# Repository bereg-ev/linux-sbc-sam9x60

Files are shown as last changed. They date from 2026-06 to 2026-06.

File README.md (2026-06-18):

# linux-sbc-sam9x60

In 2019, when I finally decided to quit Eagle PCB and move over to KiCad, this small Linux single-board computer became my first real KiCad project.  

At the same time, it was the first time I tried JLCPCB’s PCBA service—a significant improvement in efficiency. Before that, all parts of my prototypes were fully hand-assembled by me, including all the R–C components and BGAs.  

Back then, JLC only offered top-side assembly, and the SAM9X60 CPU was not available, so I went for an unconventional placement: all parts on the top side except the CPU. This way I could hand-solder the 0.8 mm BGA at home with less risk of affecting the components on the other side.

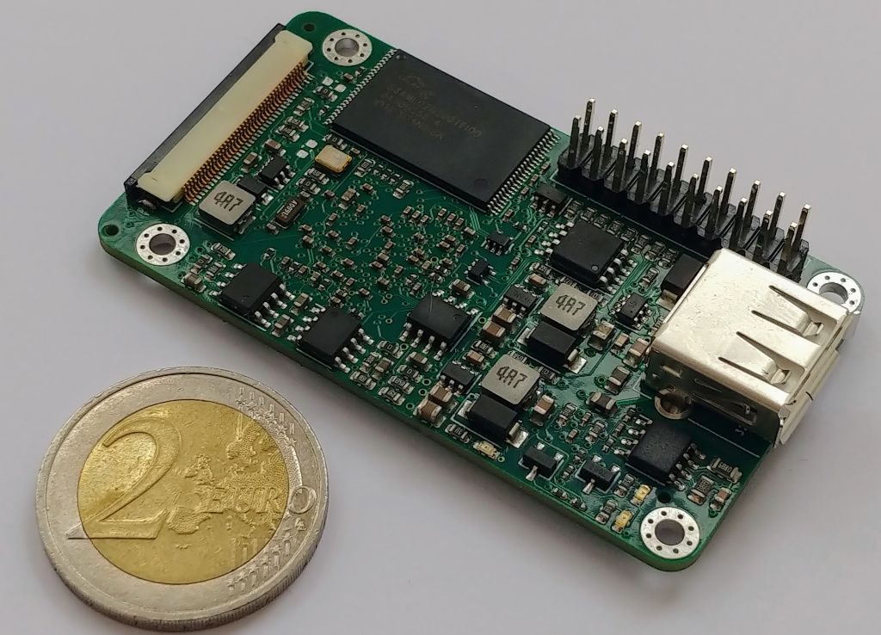
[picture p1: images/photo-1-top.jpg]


<table>
  <tr>
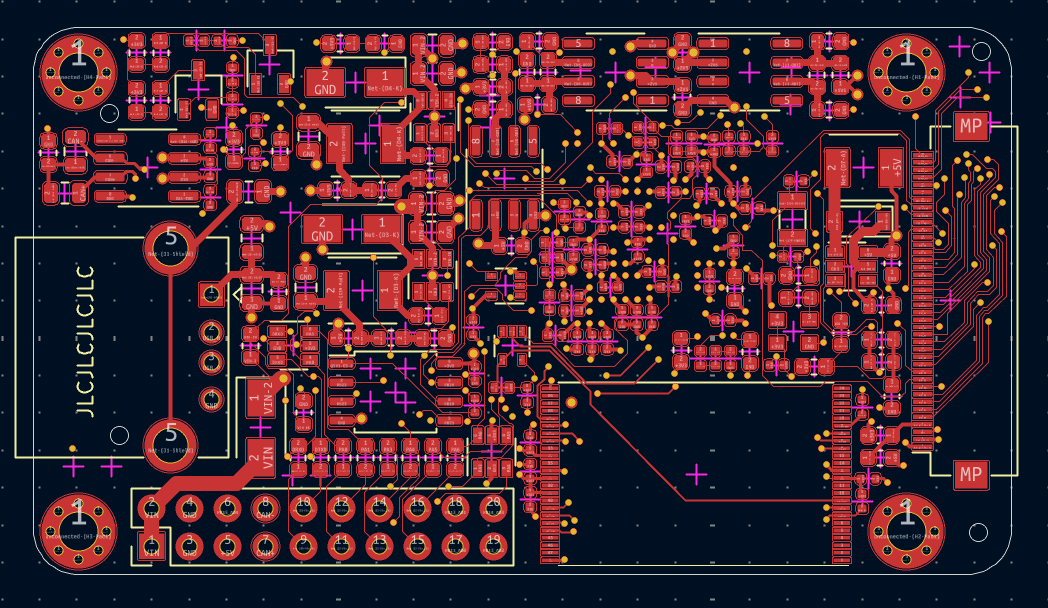
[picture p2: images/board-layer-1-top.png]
    <td></td>
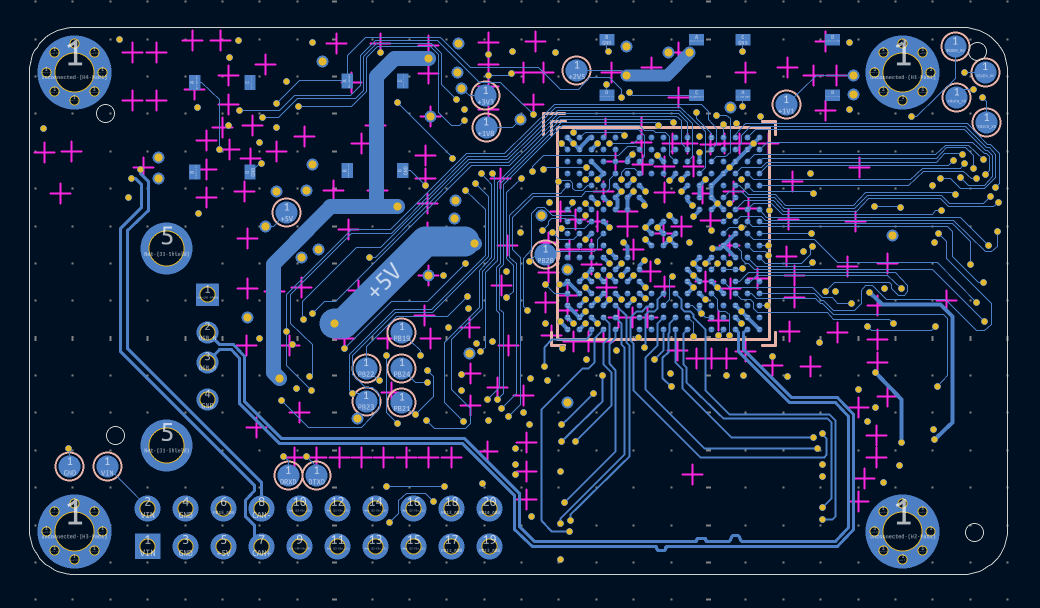
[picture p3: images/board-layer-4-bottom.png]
    <td></td>
  </tr>
  <tr>
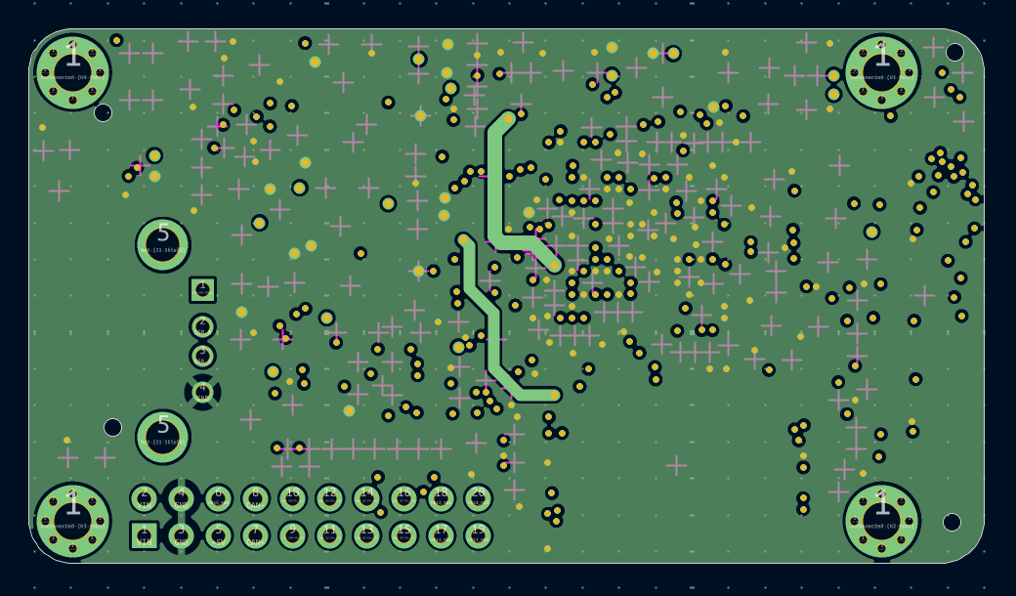
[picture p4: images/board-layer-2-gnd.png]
    <td></td>
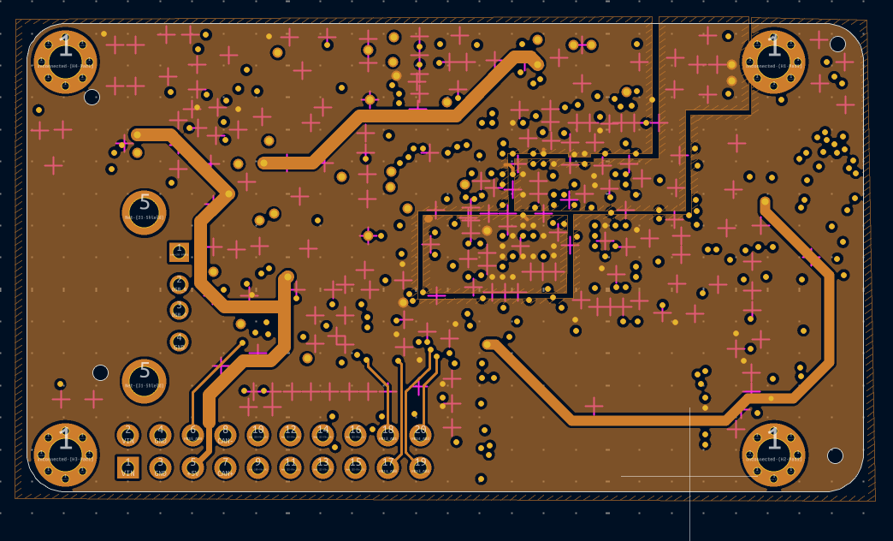
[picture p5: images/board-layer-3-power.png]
    <td></td>
  </tr>
</table>

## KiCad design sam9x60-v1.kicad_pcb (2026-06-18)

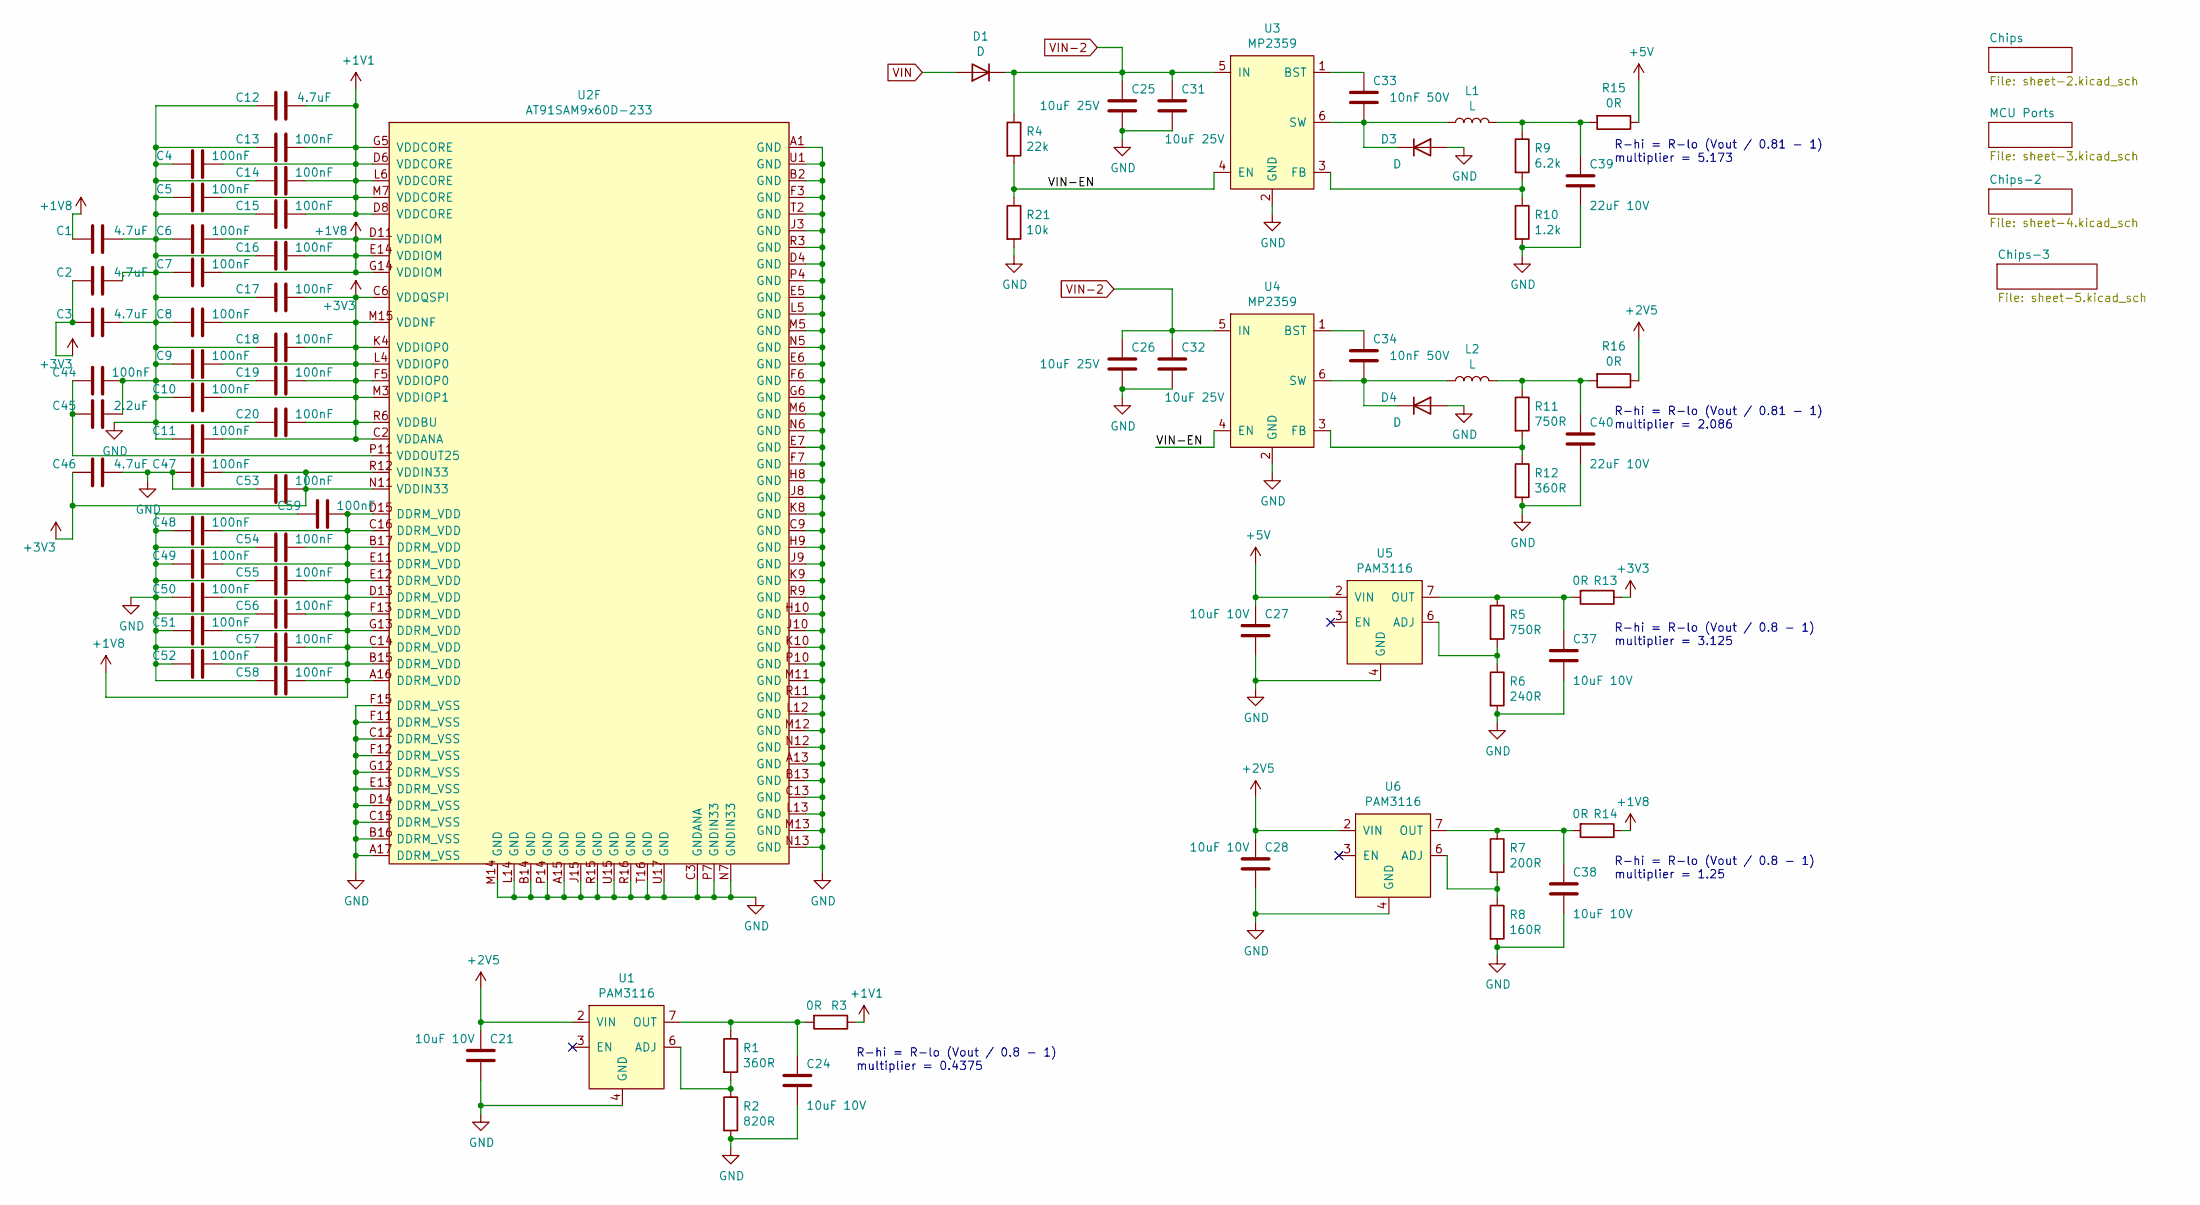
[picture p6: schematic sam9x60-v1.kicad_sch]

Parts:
C1, C2, C3, C12, C46: 4.7uF; C_0402_1005Metric; LCSC C23733
C4, C5, C6, C7, C8, C9, C10, C11, C13, C14, C15, C16, C17, C18, C19, C20, C44, C47, C48, C49, C50, C51, C52, C53, C54, C55, C56, C57, C58, C59: 100nF; C_0402_1005Metric; LCSC C1525
C21, C24, C27, C28, C37, C38: 10uF 10V; C_0603_1608Metric; LCSC C19702
C25, C26, C31, C32: 10uF 25V; C_0805_2012Metric; LCSC C15850
C33, C34: 10nF 50V; C_0603_1608Metric; LCSC C57112
C39, C40: 22uF 10V; C_0805_2012Metric; LCSC C45783
C45: 2.2uF; C_0603_1608Metric; LCSC C23630
D1, D3, D4: D; D_SMA; LCSC C14996
L1, L2: L; L-MWSA0402; LCSC C408337
R1, R12: 360R; R_0603_1608Metric; LCSC C25194
R2: 820R; R_0603_1608Metric; LCSC C23253
R3, R13, R14, R15, R16: 0R; R_0603_1608Metric; LCSC C21189
R4: 22k; R_0603_1608Metric; LCSC C31850
R5, R11: 750R; R_0603_1608Metric; LCSC C23241
R6: 240R; R_0603_1608Metric; LCSC C23350
R7: 200R; R_0603_1608Metric; LCSC C8218
R8: 160R; R_0603_1608Metric; LCSC C22814
R9: 6.2k; R_0603_1608Metric; LCSC C4260
R10: 1.2k; R_0603_1608Metric; LCSC C22765
R21: 10k; R_0603_1608Metric; LCSC C25804
U1, U5, U6: PAM3116; SOIC-8_3.9x4.9mm_P1.27mm; LCSC C481696
U2: AT91SAM9x60D-233; TFBGA-233
U3, U4: MP2359; SOT-23-6; LCSC C14259

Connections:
+1V1: C4.1, C5.1, C12.1, C13.1, C14.1, C15.1, R3.1, U2.D6 (VDDCORE), U2.D8 (VDDCORE), U2.G5 (VDDCORE), U2.L6 (VDDCORE), U2.M7 (VDDCORE); also elsewhere on the board
+1V8: C1.2, C6.1, C7.1, C16.1, C48.1, C49.1, C50.1, C51.1, C52.1, C54.1, C55.1, C56.1, C57.1, C58.1, C59.1, R14.1, U2.A16 (DDRM_VDD), U2.B15 (DDRM_VDD), U2.B17 (DDRM_VDD), U2.C14 (DDRM_VDD), U2.C16 (DDRM_VDD), U2.D11 (VDDIOM), U2.D13 (DDRM_VDD), U2.D15 (DDRM_VDD), U2.E11 (DDRM_VDD), U2.E12 (DDRM_VDD), U2.E14 (VDDIOM), U2.F13 (DDRM_VDD), U2.G13 (DDRM_VDD), U2.G14 (VDDIOM); also elsewhere on the board
+2V5: C21.1, C28.1, R16.1, U1.2 (VIN), U6.2 (VIN); also elsewhere on the board
+3V3: C2.2, C3.2, C8.1, C9.1, C10.1, C11.1, C17.1, C18.1, C19.1, C20.1, C46.2, C47.1, C53.1, R13.1, U2.C2 (VDDANA), U2.C6 (VDDQSPI), U2.F5 (VDDIOP0), U2.K4 (VDDIOP0), U2.L4 (VDDIOP0), U2.M3 (VDDIOP1), U2.M15 (VDDNF), U2.N11 (VDDIN33), U2.R6 (VDDBU), U2.R12 (VDDIN33); also elsewhere on the board
+5V: C27.1, R15.1, U5.2 (VIN); also elsewhere on the board
/VIN-EN: R4.2, R21.1, U3.4 (EN), U4.4 (EN)
GND: C1.1, C2.1, C3.1, C4.2, C5.2, C6.2, C7.2, C8.2, C9.2, C10.2, C11.2, C12.2, C13.2, C14.2, C15.2, C16.2, C17.2, C18.2, C19.2, C20.2, C21.2, C24.2, C25.2, C26.2, C27.2, C28.2, C31.2, C32.2, C37.2, C38.2, C39.2, C40.2, C44.1, C45.1, C46.1, C47.2, C48.2, C49.2, C50.2, C51.2, C52.2, C53.2, C54.2, C55.2, C56.2, C57.2, C58.2, C59.2, D3.2 (A), D4.2 (A), R2.2, R6.2, R8.2, R10.2, R12.2, R21.2, U1.4 (GND), U2.A1 (GND), U2.A13 (GND), U2.A15 (GND), U2.A17 (DDRM_VSS), U2.B2 (GND), U2.B13 (GND), U2.B14 (GND), U2.B16 (DDRM_VSS), U2.C3 (GNDANA), U2.C9 (GND), U2.C12 (DDRM_VSS), U2.C13 (GND), U2.C15 (DDRM_VSS), U2.D4 (GND), U2.D14 (DDRM_VSS), U2.E5 (GND), U2.E6 (GND), U2.E7 (GND), U2.E13 (DDRM_VSS), U2.F3 (GND), U2.F6 (GND), U2.F7 (GND), U2.F11 (DDRM_VSS), U2.F12 (DDRM_VSS), U2.F15 (DDRM_VSS), U2.G6 (GND), U2.G12 (DDRM_VSS), U2.H8 (GND), U2.H9 (GND), U2.H10 (GND), U2.J3 (GND), U2.J8 (GND), U2.J9 (GND), U2.J10 (GND), U2.J15 (GND), U2.K8 (GND), U2.K9 (GND), U2.K10 (GND), U2.L5 (GND), U2.L12 (GND), U2.L13 (GND), U2.L14 (GND), U2.M5 (GND), U2.M6 (GND), U2.M11 (GND), U2.M12 (GND), U2.M13 (GND), U2.M14 (GND), U2.N5 (GND), U2.N6 (GND), U2.N7 (GNDIN33), U2.N12 (GND), U2.N13 (GND), U2.P4 (GND), U2.P7 (GNDIN33), U2.P10 (GND), U2.P14 (GND), U2.R3 (GND), U2.R9 (GND), U2.R11 (GND), U2.R15 (GND), U2.R16 (GND), U2.T2 (GND), U2.T16 (GND), U2.U1 (GND), U2.U15 (GND), U2.U17 (GND), U3.2 (GND), U4.2 (GND), U5.4 (GND), U6.4 (GND); also elsewhere on the board
unnamed: C39.1, L1.2, R9.1, R15.2
unnamed: C40.1, L2.2, R11.1, R16.2
unnamed: C33.2, D3.1 (K), L1.1, U3.6 (SW)
unnamed: C34.2, D4.1 (K), L2.1, U4.6 (SW)
unnamed: R1.2, R2.1, U1.6 (ADJ)
unnamed: C24.1, R1.1, R3.2, U1.7 (OUT)
unnamed: C44.2, C45.2, U2.P11 (VDDOUT25)
unnamed: C33.1, U3.1 (BST)
unnamed: R9.2, R10.1, U3.3 (FB)
unnamed: C34.1, U4.1 (BST)
unnamed: R11.2, R12.1, U4.3 (FB)
unnamed: R5.2, R6.1, U5.6 (ADJ)
unnamed: C37.1, R5.1, R13.2, U5.7 (OUT)
unnamed: R7.2, R8.1, U6.6 (ADJ)
unnamed: C38.1, R7.1, R14.2, U6.7 (OUT)
VIN: D1.2 (A); also elsewhere on the board
VIN-2: C25.1, C26.1, C31.1, C32.1, D1.1 (K), R4.1, U3.5 (IN), U4.5 (IN)

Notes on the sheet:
R-hi = R-lo (Vout / 0.8 - 1) multiplier = 3.125
R-hi = R-lo (Vout / 0.8 - 1) multiplier = 0.4375
R-hi = R-lo (Vout / 0.81 - 1) multiplier = 2.086
R-hi = R-lo (Vout / 0.81 - 1) multiplier = 5.173
R-hi = R-lo (Vout / 0.8 - 1) multiplier = 1.25

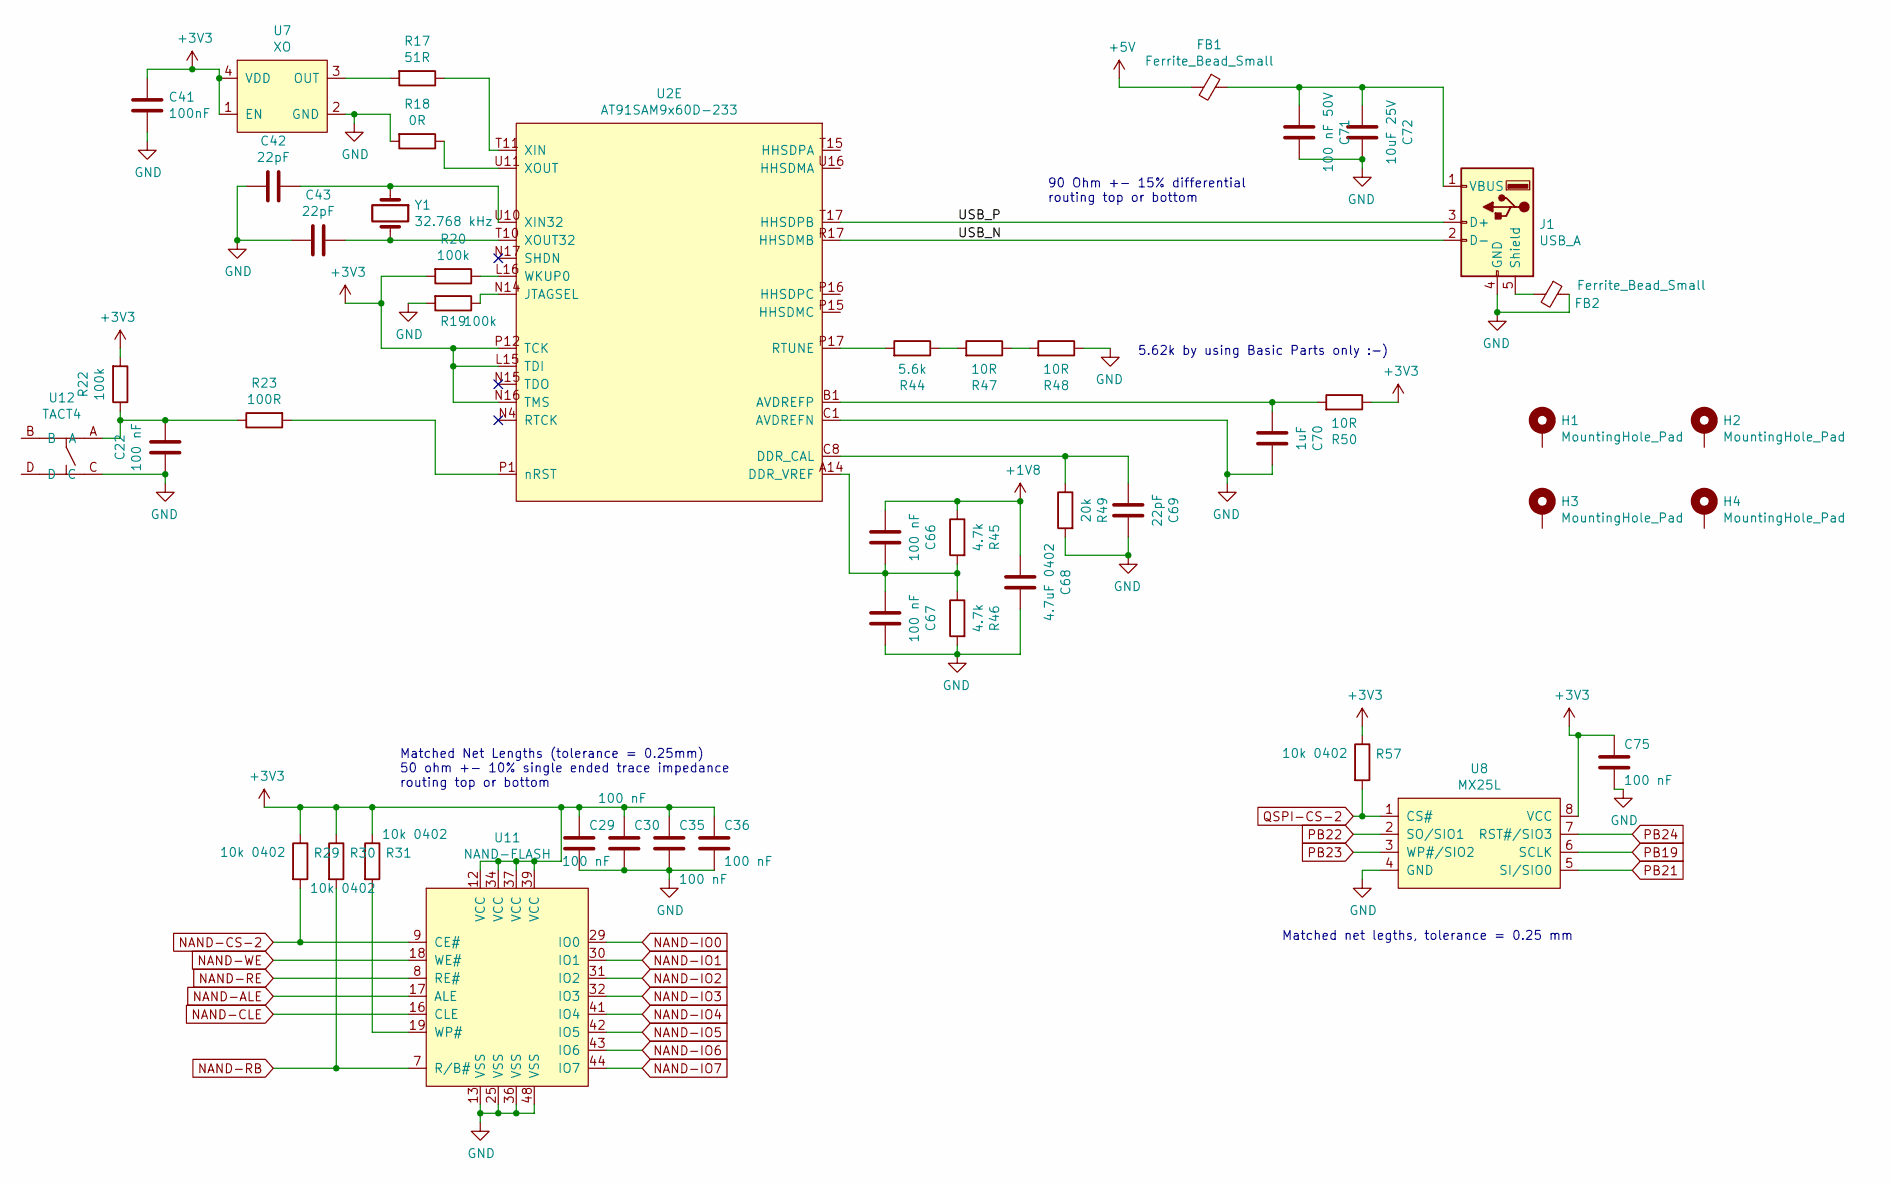
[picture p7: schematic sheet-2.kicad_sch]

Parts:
C22: 100 nF; C_0402_1005Metric
C29, C30, C35, C36, C66, C67, C75: 100 nF; C_0402_1005Metric; LCSC C1525
C41: 100nF; C_0402_1005Metric
C42, C43, C69: 22pF; C_0402_1005Metric; LCSC C1555
C68: 4.7uF 0402; C_0402_1005Metric; LCSC C23733
C70: 1uF; C_0402_1005Metric; LCSC C52923
C71: 100 nF 50V; C_0603_1608Metric; LCSC C57112
C72: 10uF 25V; C_0805_2012Metric; LCSC C15850
FB1, FB2: Ferrite_Bead_Small; R_0805_2012Metric; LCSC C1015
H1, H2, H3, H4: MountingHole_Pad; MountingHole_2.5mm_Pad_Via
J1: USB_A; USB_A_CONNFLY_DS1095-WNR0
R17: 51R; R_0603_1608Metric; LCSC C23197
R18: 0R; R_0603_1608Metric; LCSC C21189
R19, R20: 100k; R_0603_1608Metric; LCSC C25803
R22: 100k; R_0402_1005Metric; LCSC C25741
R23: 100R; R_0402_1005Metric; LCSC C25076
R29, R30, R31, R57: 10k 0402; R_0402_1005Metric; LCSC C25744
R44: 5.6k; R_0402_1005Metric; LCSC C25908
R45, R46: 4.7k; R_0402_1005Metric; LCSC C25900
R47, R48, R50: 10R; R_0402_1005Metric; LCSC C25077
R49: 20k; R_0402_1005Metric; LCSC C25765
U2: AT91SAM9x60D-233; TFBGA-233
U7: XO; Oscillator_SMD_EuroQuartz_XO32-4Pin_3.2x2.5mm; LCSC C295524
U8: MX25L; SOIC-8_5.23x5.23mm_P1.27mm; LCSC C71945
U11: NAND-FLASH; TSOP-I-48_18.4x12mm_P0.5mm; LCSC C92089
U12: TACT4; Tact-TS-551; LCSC C318887
Y1: 32.768 kHz; Crystal_SMD_3215-2Pin_3.2x1.5mm; LCSC C32346

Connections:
+1V8: C66.2, C68.2, R45.1; also elsewhere on the board
+3V3: C29.1, C30.1, C35.1, C36.1, C41.2, C75.1, R20.2, R22.2, R29.1, R30.1, R31.1, R50.1, R57.1, U2.L15 (TDI), U2.N16 (TMS), U2.P12 (TCK), U7.1 (EN), U7.4 (VDD), U8.8 (VCC), U11.12 (VCC), U11.34 (VCC), U11.37 (VCC), U11.39 (VCC); also elsewhere on the board
+5V: FB1.2; also elsewhere on the board
/Chips/USB_N: J1.2 (D-), U2.R17 (HHSDMB)
/Chips/USB_P: J1.3 (D+), U2.T17 (HHSDPB)
GND: C22.1, C29.2, C30.2, C35.2, C36.2, C41.1, C42.2, C43.2, C67.1, C68.1, C69.1, C70.1, C71.1, C72.1, C75.2, FB2.1, J1.4 (GND), R18.2, R19.2, R46.2, R48.1, R49.2, U2.C1 (AVDREFN), U7.2 (GND), U8.4 (GND), U11.13 (VSS), U11.25 (VSS), U11.36 (VSS), U11.48 (VSS), U12.C; also elsewhere on the board
NAND-ALE: U11.17 (ALE); also elsewhere on the board
NAND-CLE: U11.16 (CLE); also elsewhere on the board
NAND-CS-2: R29.2, U11.9 (CE#); also elsewhere on the board
NAND-IO0: U11.29 (IO0); also elsewhere on the board
NAND-IO1: U11.30 (IO1); also elsewhere on the board
NAND-IO2: U11.31 (IO2); also elsewhere on the board
NAND-IO3: U11.32 (IO3); also elsewhere on the board
NAND-IO4: U11.41 (IO4); also elsewhere on the board
NAND-IO5: U11.42 (IO5); also elsewhere on the board
NAND-IO6: U11.43 (IO6); also elsewhere on the board
NAND-IO7: U11.44 (IO7); also elsewhere on the board
NAND-RB: R30.2, U11.7 (R/B#); also elsewhere on the board
NAND-RE: U11.8 (RE#); also elsewhere on the board
NAND-WE: U11.18 (WE#); also elsewhere on the board
unnamed: C22.2, R22.1, R23.1, U12.A
unnamed: FB2.2, J1.5 (Shield)
unnamed: C71.2, C72.2, FB1.1, J1.1 (VBUS)
unnamed: R44.1, R47.2
unnamed: R47.1, R48.2
unnamed: C70.2, R50.2, U2.B1 (AVDREFP)
unnamed: C69.2, R49.1, U2.C8 (DDR_CAL)
unnamed: C66.1, C67.2, R45.2, R46.1, U2.A14 (DDR_VREF)
unnamed: R19.1, U2.N14 (JTAGSEL)
unnamed: R44.2, U2.P17 (RTUNE)
unnamed: R20.1, U2.L16 (WKUP0)
unnamed: C42.1, U2.U10 (XIN32), Y1.1
unnamed: R17.1, U2.T11 (XIN)
unnamed: C43.1, U2.T10 (XOUT32), Y1.2
unnamed: R18.1, U2.U11 (XOUT)
unnamed: R23.2, U2.P1 (nRST)
unnamed: R17.2, U7.3 (OUT)
unnamed: R31.2, U11.19 (WP#)
PB19: U8.6 (SCLK); also elsewhere on the board
PB21: U8.5 (SI/SIO0); also elsewhere on the board
PB22: U8.2 (SO/SIO1); also elsewhere on the board
PB23: U8.3 (WP#/SIO2); also elsewhere on the board
PB24: U8.7 (RST#/SIO3); also elsewhere on the board
QSPI-CS-2: R57.2, U8.1 (CS#)

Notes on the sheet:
Matched net legths, tolerance = 0.25 mm
5.62k by using Basic Parts only :-)
90 Ohm +- 15% differential routing top or bottom
Matched Net Lengths (tolerance = 0.25mm) 50 ohm +- 10% single ended trace impedance routing top or bottom

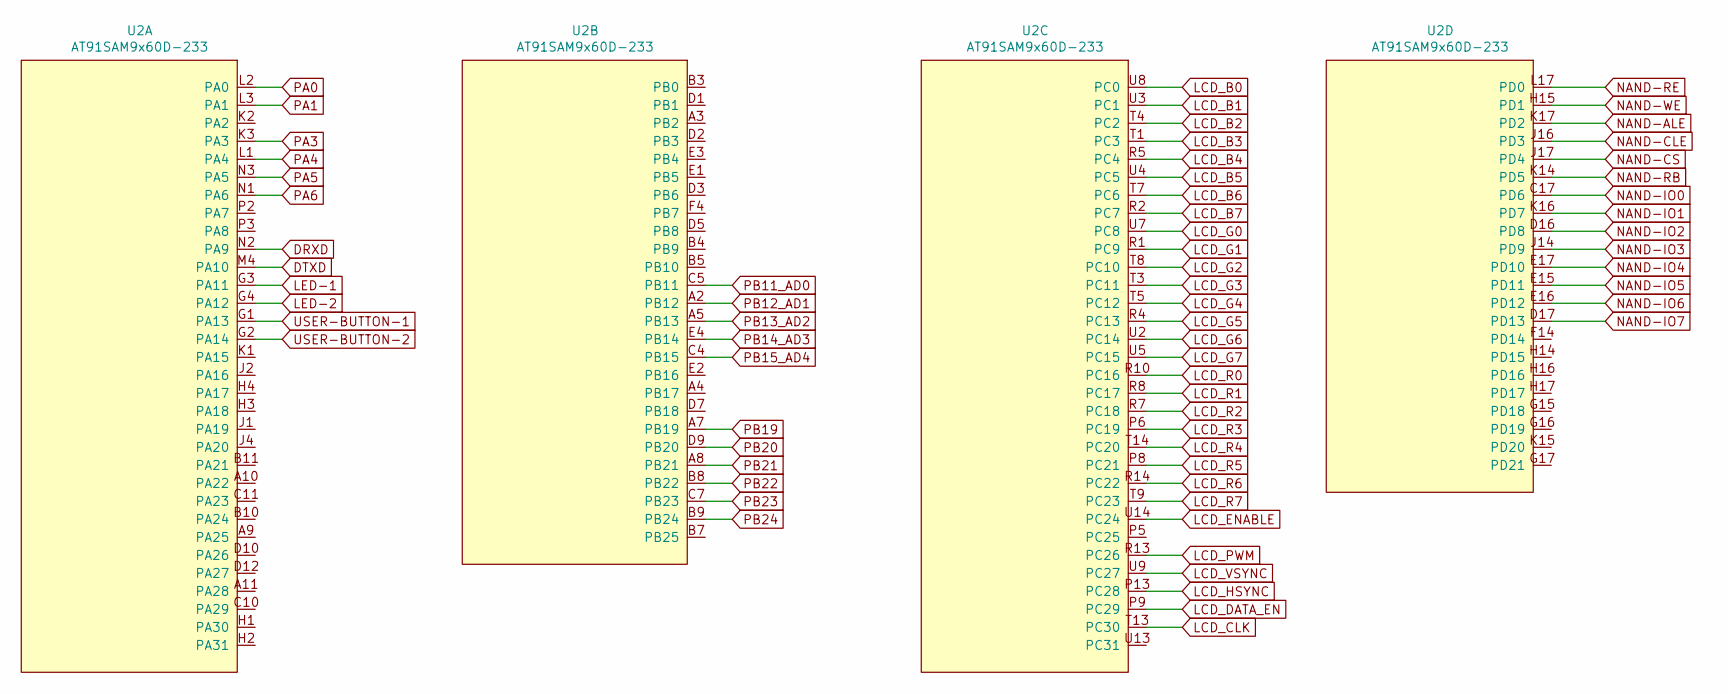
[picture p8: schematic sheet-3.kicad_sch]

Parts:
U2: AT91SAM9x60D-233

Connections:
DRXD: U2.N2 (PA9); also elsewhere on the board
DTXD: U2.M4 (PA10); also elsewhere on the board
LCD_B0: U2.U8 (PC0); also elsewhere on the board
LCD_B1: U2.U3 (PC1); also elsewhere on the board
LCD_B2: U2.T4 (PC2); also elsewhere on the board
LCD_B3: U2.T1 (PC3); also elsewhere on the board
LCD_B4: U2.R5 (PC4); also elsewhere on the board
LCD_B5: U2.U4 (PC5); also elsewhere on the board
LCD_B6: U2.T7 (PC6); also elsewhere on the board
LCD_B7: U2.R2 (PC7); also elsewhere on the board
LCD_CLK: U2.T13 (PC30); also elsewhere on the board
LCD_DATA_EN: U2.P9 (PC29); also elsewhere on the board
LCD_ENABLE: U2.U14 (PC24); also elsewhere on the board
LCD_G0: U2.U7 (PC8); also elsewhere on the board
LCD_G1: U2.R1 (PC9); also elsewhere on the board
LCD_G2: U2.T8 (PC10); also elsewhere on the board
LCD_G3: U2.T3 (PC11); also elsewhere on the board
LCD_G4: U2.T5 (PC12); also elsewhere on the board
LCD_G5: U2.R4 (PC13); also elsewhere on the board
LCD_G6: U2.U2 (PC14); also elsewhere on the board
LCD_G7: U2.U5 (PC15); also elsewhere on the board
LCD_HSYNC: U2.P13 (PC28); also elsewhere on the board
LCD_PWM: U2.R13 (PC26); also elsewhere on the board
LCD_R0: U2.R10 (PC16); also elsewhere on the board
LCD_R1: U2.R8 (PC17); also elsewhere on the board
LCD_R2: U2.R7 (PC18); also elsewhere on the board
LCD_R3: U2.P6 (PC19); also elsewhere on the board
LCD_R4: U2.T14 (PC20); also elsewhere on the board
LCD_R5: U2.P8 (PC21); also elsewhere on the board
LCD_R6: U2.R14 (PC22); also elsewhere on the board
LCD_R7: U2.T9 (PC23); also elsewhere on the board
LCD_VSYNC: U2.U9 (PC27); also elsewhere on the board
LED-1: U2.G3 (PA11); also elsewhere on the board
LED-2: U2.G4 (PA12); also elsewhere on the board
NAND-ALE: U2.K17 (PD2); also elsewhere on the board
NAND-CLE: U2.J16 (PD3); also elsewhere on the board
NAND-CS: U2.J17 (PD4); also elsewhere on the board
NAND-IO0: U2.C17 (PD6); also elsewhere on the board
NAND-IO1: U2.K16 (PD7); also elsewhere on the board
NAND-IO2: U2.D16 (PD8); also elsewhere on the board
NAND-IO3: U2.J14 (PD9); also elsewhere on the board
NAND-IO4: U2.E17 (PD10); also elsewhere on the board
NAND-IO5: U2.E15 (PD11); also elsewhere on the board
NAND-IO6: U2.E16 (PD12); also elsewhere on the board
NAND-IO7: U2.D17 (PD13); also elsewhere on the board
NAND-RB: U2.K14 (PD5); also elsewhere on the board
NAND-RE: U2.L17 (PD0); also elsewhere on the board
NAND-WE: U2.H15 (PD1); also elsewhere on the board
PA0: U2.L2 (PA0); also elsewhere on the board
PA1: U2.L3 (PA1); also elsewhere on the board
PA3: U2.K3 (PA3); also elsewhere on the board
PA4: U2.L1 (PA4); also elsewhere on the board
PA5: U2.N3 (PA5); also elsewhere on the board
PA6: U2.N1 (PA6); also elsewhere on the board
PB11_AD0: U2.C5 (PB11); also elsewhere on the board
PB12_AD1: U2.A2 (PB12); also elsewhere on the board
PB13_AD2: U2.A5 (PB13); also elsewhere on the board
PB14_AD3: U2.E4 (PB14); also elsewhere on the board
PB15_AD4: U2.C4 (PB15); also elsewhere on the board
PB19: U2.A7 (PB19); also elsewhere on the board
PB20: U2.D9 (PB20); also elsewhere on the board
PB21: U2.A8 (PB21); also elsewhere on the board
PB22: U2.B8 (PB22); also elsewhere on the board
PB23: U2.C7 (PB23); also elsewhere on the board
PB24: U2.B9 (PB24); also elsewhere on the board
USER-BUTTON-1: U2.G1 (PA13); also elsewhere on the board
USER-BUTTON-2: U2.G2 (PA14); also elsewhere on the board

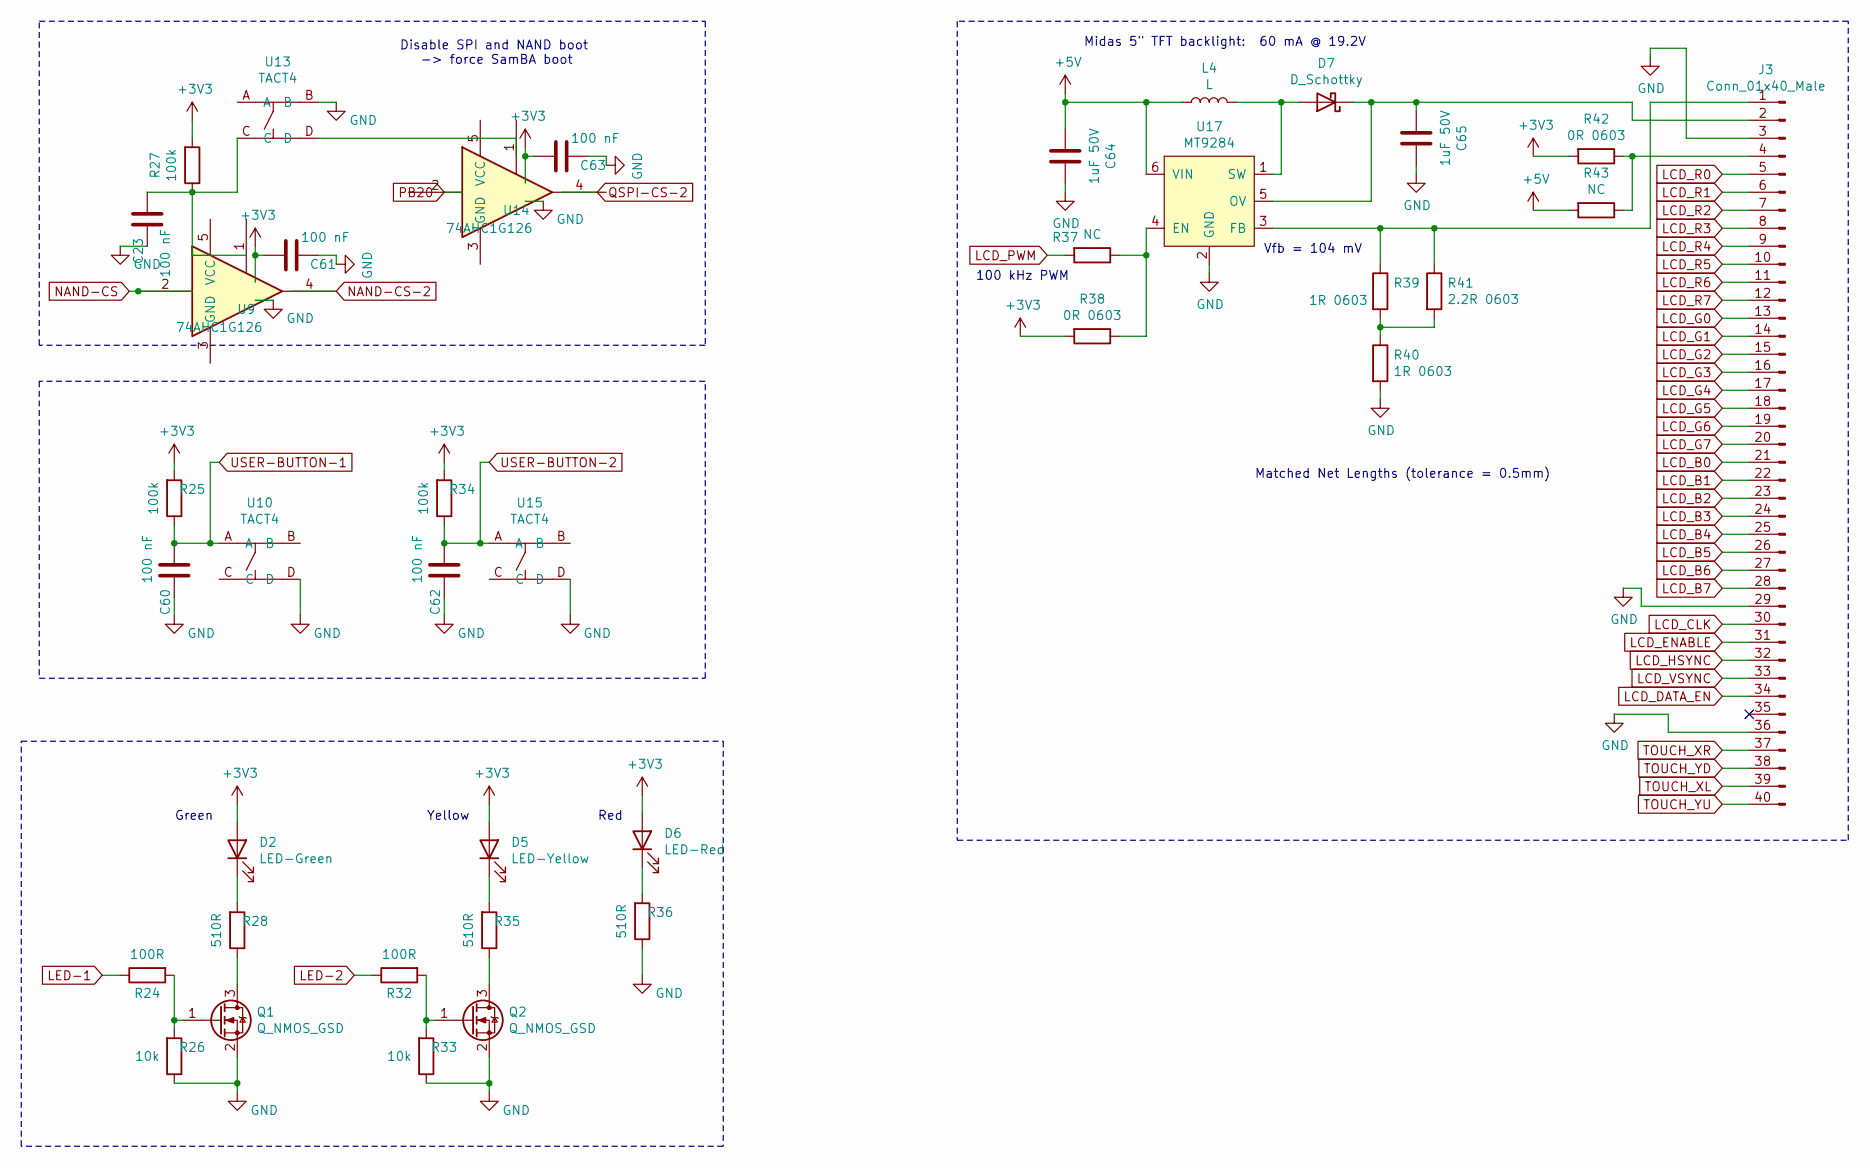
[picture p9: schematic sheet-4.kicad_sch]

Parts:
C23, C60, C61, C62, C63: 100 nF; C_0402_1005Metric; LCSC C1525
C64, C65: 1uF 50V; C_0603_1608Metric; LCSC C15849
D2: LED-Green; R_0603_1608Metric; LCSC C72043
D5: LED-Yellow; R_0603_1608Metric; LCSC C72038
D6: LED-Red; R_0603_1608Metric; LCSC C2286
D7: D_Schottky; D_SOD-123; LCSC C8598
J3: Conn_01x40_Male; Hirose_FH12-40S-0.5SH_1x40-1MP_P0.50mm_Horizontal
L4: L; L-MWSA0402; LCSC C408337
Q1, Q2: Q_NMOS_GSD; TSOT-23; LCSC C8545
R24, R32: 100R; R_0402_1005Metric; LCSC C25076
R25, R34: 100k; R_0603_1608Metric; LCSC C25803
R26, R33: 10k; R_0402_1005Metric; LCSC C25744
R27: 100k; R_0402_1005Metric; LCSC C25741
R28, R35, R36: 510R; R_0603_1608Metric; LCSC C23193
R37, R43: NC; R_0603_1608Metric
R38, R42: 0R 0603; R_0603_1608Metric; LCSC C21189
R39, R40: 1R 0603; R_0603_1608Metric; LCSC C22936
R41: 2.2R 0603; R_0603_1608Metric; LCSC C22939
U9, U14: 74AHC1G126; SOT-353_SC-70-5; LCSC C92637
U10, U13, U15: TACT4; Tact-TS-551; LCSC C318887
U17: MT9284; SOT-23-6; LCSC C181780

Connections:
+3V3: C61.2, C63.2, D2.2 (A), D5.2 (A), D6.2 (A), R25.2, R27.2, R34.2, R38.2, R42.2; also elsewhere on the board
+5V: C64.2, L4.1, R43.2, U17.6 (VIN); also elsewhere on the board
GND: C23.1, C60.1, C61.1, C62.1, C63.1, C64.1, C65.1, J3.3, J3.29, J3.36, Q1.2 (S), Q2.2 (S), R26.1, R33.1, R36.1, R40.2, U10.D, U13.B, U15.D, U17.2 (GND); also elsewhere on the board
LCD_B0: J3.21; also elsewhere on the board
LCD_B1: J3.22; also elsewhere on the board
LCD_B2: J3.23; also elsewhere on the board
LCD_B3: J3.24; also elsewhere on the board
LCD_B4: J3.25; also elsewhere on the board
LCD_B5: J3.26; also elsewhere on the board
LCD_B6: J3.27; also elsewhere on the board
LCD_B7: J3.28; also elsewhere on the board
LCD_CLK: J3.30; also elsewhere on the board
LCD_DATA_EN: J3.34; also elsewhere on the board
LCD_ENABLE: J3.31; also elsewhere on the board
LCD_G0: J3.13; also elsewhere on the board
LCD_G1: J3.14; also elsewhere on the board
LCD_G2: J3.15; also elsewhere on the board
LCD_G3: J3.16; also elsewhere on the board
LCD_G4: J3.17; also elsewhere on the board
LCD_G5: J3.18; also elsewhere on the board
LCD_G6: J3.19; also elsewhere on the board
LCD_G7: J3.20; also elsewhere on the board
LCD_HSYNC: J3.32; also elsewhere on the board
LCD_PWM: R37.2; also elsewhere on the board
LCD_R0: J3.5; also elsewhere on the board
LCD_R1: J3.6; also elsewhere on the board
LCD_R2: J3.7; also elsewhere on the board
LCD_R3: J3.8; also elsewhere on the board
LCD_R4: J3.9; also elsewhere on the board
LCD_R5: J3.10; also elsewhere on the board
LCD_R6: J3.11; also elsewhere on the board
LCD_R7: J3.12; also elsewhere on the board
LCD_VSYNC: J3.33; also elsewhere on the board
LED-1: R24.1; also elsewhere on the board
LED-2: R32.1; also elsewhere on the board
NAND-CS: U9.2; also elsewhere on the board
NAND-CS-2: U9.4; also elsewhere on the board
unnamed: C23.2, R27.1, U13.C
unnamed: D2.1 (K), R28.2
unnamed: D5.1 (K), R35.2
unnamed: D6.1 (K), R36.2
unnamed: D7.2 (A), L4.2, U17.1 (SW)
unnamed: C65.2, D7.1 (K), J3.2, U17.5 (OV)
unnamed: J3.1, R39.1, R41.1, U17.3 (FB)
unnamed: J3.4, R42.1, R43.1
unnamed: Q1.3 (D), R28.1
unnamed: Q1.1 (G), R24.2, R26.2
unnamed: Q2.3 (D), R35.1
unnamed: Q2.1 (G), R32.2, R33.2
unnamed: R39.2, R40.1, R41.2
unnamed: R37.1, R38.1, U17.4 (EN)
TOUCH_XL: J3.39; also elsewhere on the board
TOUCH_XR: J3.37; also elsewhere on the board
TOUCH_YD: J3.38; also elsewhere on the board
TOUCH_YU: J3.40; also elsewhere on the board
USER-BUTTON-1: C60.2, R25.1, U10.A; also elsewhere on the board
USER-BUTTON-2: C62.2, R34.1, U15.A; also elsewhere on the board

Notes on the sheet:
Matched Net Lengths (tolerance = 0.5mm)
Midas 5" TFT backlight: 60 mA @ 19.2V
Yellow
Disable SPI and NAND boot -> force SamBA boot
Vfb = 104 mV
Green
Red
100 kHz PWM

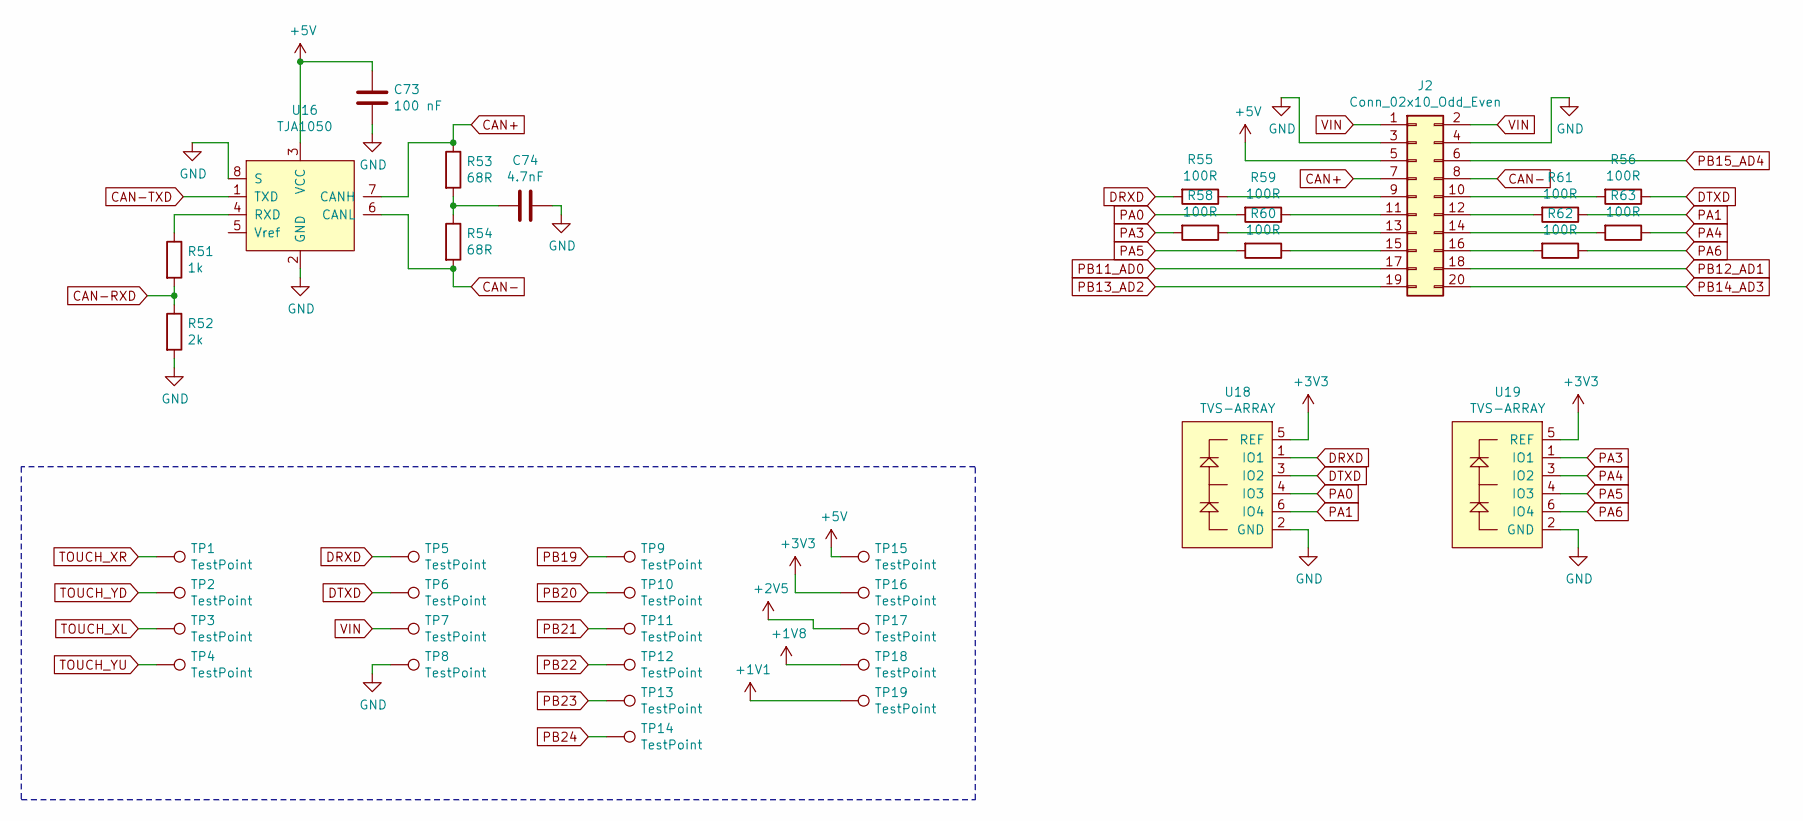
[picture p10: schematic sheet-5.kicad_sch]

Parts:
C73: 100 nF; R_0402_1005Metric; LCSC C1525
C74: 4.7nF; R_0603_1608Metric; LCSC C53987
J2: Conn_02x10_Odd_Even; PinHeader_2x10_P2.54mm_Vertical
R51: 1k; R_0402_1005Metric; LCSC C11702
R52: 2k; R_0402_1005Metric; LCSC C4109
R53, R54: 68R; R_0805_2012Metric; LCSC C17802
R55, R56, R58, R59, R60, R61, R62, R63: 100R; R_0603_1608Metric; LCSC C22775
TP1, TP2, TP3, TP4, TP5, TP6, TP7, TP8, TP9, TP10, TP11, TP12, TP13, TP14, TP15, TP16, TP17, TP18, TP19: TestPoint; TestPoint_Pad_D1.5mm
U16: TJA1050; SOIC-8_3.9x4.9mm_P1.27mm; LCSC C6952
U18, U19: TVS-ARRAY; SOT-23-6; LCSC C85364

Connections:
+1V1: TP19.1; also elsewhere on the board
+1V8: TP18.1; also elsewhere on the board
+2V5: TP17.1; also elsewhere on the board
+3V3: TP16.1, U18.5 (REF), U19.5 (REF); also elsewhere on the board
+5V: C73.2, J2.5, TP15.1, U16.3 (VCC); also elsewhere on the board
CAN+: J2.7, R53.1, U16.7 (CANH)
CAN-: J2.8, R54.2, U16.6 (CANL)
CAN-RXD: R51.2, R52.1
CAN-TXD: U16.1 (TXD)
DRXD: R55.2, TP5.1, U18.1 (IO1); also elsewhere on the board
DTXD: R56.1, TP6.1, U18.3 (IO2); also elsewhere on the board
GND: C73.1, C74.1, J2.3, J2.4, R52.2, TP8.1, U16.2 (GND), U16.8 (S), U18.2 (GND), U19.2 (GND); also elsewhere on the board
unnamed: C74.2, R53.2, R54.1
unnamed: J2.9, R55.1
unnamed: J2.10, R56.2
unnamed: J2.11, R59.1
unnamed: J2.12, R61.2
unnamed: J2.13, R58.1
unnamed: J2.14, R63.2
unnamed: J2.15, R60.1
unnamed: J2.16, R62.2
unnamed: R51.1, U16.4 (RXD)
PA0: R59.2, U18.4 (IO3); also elsewhere on the board
PA1: R61.1, U18.6 (IO4); also elsewhere on the board
PA3: R58.2, U19.1 (IO1); also elsewhere on the board
PA4: R63.1, U19.3 (IO2); also elsewhere on the board
PA5: R60.2, U19.4 (IO3); also elsewhere on the board
PA6: R62.1, U19.6 (IO4); also elsewhere on the board
PB11_AD0: J2.17; also elsewhere on the board
PB12_AD1: J2.18; also elsewhere on the board
PB13_AD2: J2.19; also elsewhere on the board
PB14_AD3: J2.20; also elsewhere on the board
PB15_AD4: J2.6; also elsewhere on the board
PB19: TP9.1; also elsewhere on the board
PB20: TP10.1; also elsewhere on the board
PB21: TP11.1; also elsewhere on the board
PB22: TP12.1; also elsewhere on the board
PB23: TP13.1; also elsewhere on the board
PB24: TP14.1; also elsewhere on the board
TOUCH_XL: TP3.1; also elsewhere on the board
TOUCH_XR: TP1.1; also elsewhere on the board
TOUCH_YD: TP2.1; also elsewhere on the board
TOUCH_YU: TP4.1; also elsewhere on the board
VIN: J2.1, J2.2, TP7.1; also elsewhere on the board

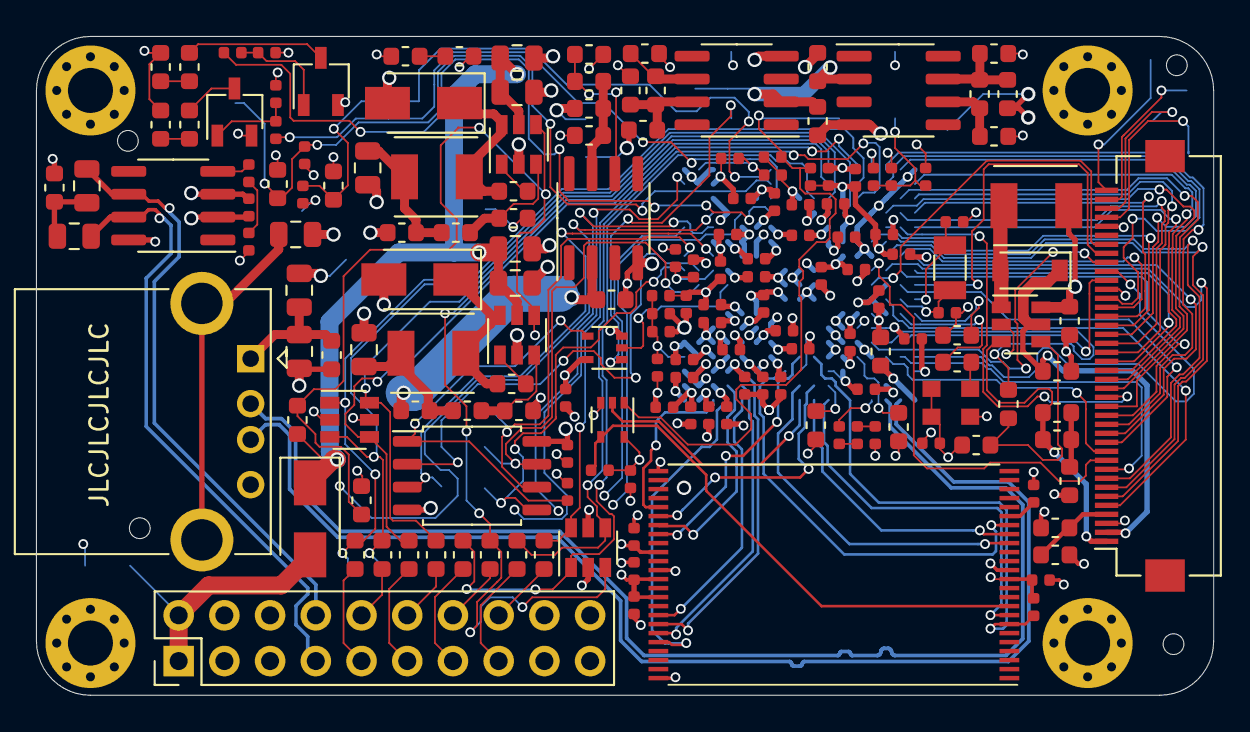
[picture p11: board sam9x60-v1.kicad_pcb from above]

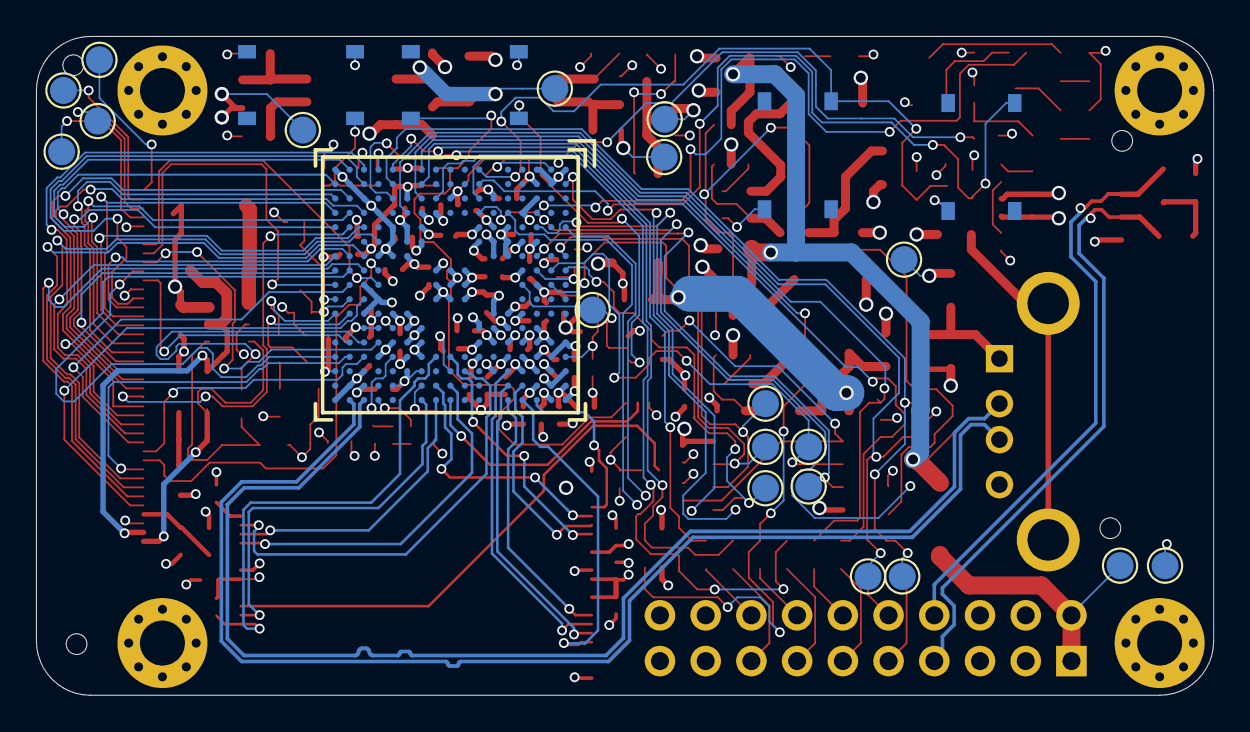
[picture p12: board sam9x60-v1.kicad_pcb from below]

Board: 4 copper layers, 65.4 x 36.6 mm, 198 parts (24 on the bottom side), 144 nets.

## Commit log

2026-06-18 initial commit: JTAGSEL fix, updated sch + brd in Kicad 7, board layer images and photo of the physical board with a coin
    [sam9x60-v1.kicad_pcb, sam9x60-v1.kicad_sch, sam9x60-v1.sch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]
2026-06-18 README with project history and images
    Added detailed project background and assembly process.
